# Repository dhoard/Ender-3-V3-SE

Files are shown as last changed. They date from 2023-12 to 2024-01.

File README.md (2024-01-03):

## Ender 3 V3 SE Mods

The project contains Ender3 V3 SE modifications.

[X-axis linear rail](https://github.com/dhoard/Ender3-V3-SE/tree/main/x-axis-linear-rail)

[3 Point Carriage Adapter](https://github.com/dhoard/Ender-3-V3-SE/tree/main/3-point-carriage-adapter)

## License
[CC BY-NC-SA 4.0](https://creativecommons.org/licenses/by-nc-sa/4.0/)

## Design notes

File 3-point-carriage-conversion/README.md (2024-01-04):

## 3 Point Carriage Conversion 

## Disclaimer

Install and use at your own risk. Not responsible for you, your machine, or any damages.

### Tools

A soldering iron or heat set insert tool is required

### Parts list:

1 x [3 Point Carriage Adapter (Top)](3%20Point%20Carriage%20Adapter%20%28Top%29.stl)
- PETG or ABS, 50% tri-hexagon infill, .3mm layer height, 8 walls

1 x [3 Point Carriage Adapter (Bottom)](3%20Point%20Carriage%20Adapter%20%28Bottom%29.stl)
- 50% tri-hexagon infill, .3mm layer height, 8 walls
- PETG or ABS

1 x [Bed Leveling Knob](Bed%20Leveling%20Knob.stl)

2 x Ender 3 25mm Yellow Springs

1 x M4 x 35mm screw

4 x M4 x 8mm screws

5 x M4 nuts

### Instructions

1. Unplug the printer
2. Remove the build surface
3. Remove the build plate
4. Use a heat set insert tool or soldering iron to set an M4 nut into the Bed Leveling Knob
5. Insert the M4 x 35mm screw into the 3 Point Carriage Adapter (Top) part
 - The fit is snug on purpose to help hold the screw
 - You may need to heat set the screw head into the part
6. Attach the 3 Point Carriage Adapter (Top) part to the right side of the build plate with 2 x M4 x 8mm screws and M4 nuts
7. Attached the 3 Point Carriage Adapter (Bottom) part to the right side of the carriage with 2 x M4 x 8mm screws and M4 nuts
- The ridges should be pointing up
8. Move a 16mm spacer from the right side to the left front corner (strain gauge)
9. Insert a spring between the left side rear build plate and wiring strain bracket
- **BE CAREFUL OR YOU COULD DAMAGE/DISCONNECT YOU BUILD PLATE HEATER WIRES**
10. Re-install the build plate
- When compressing the springs, compress (squeeze) the carriage and build plate together to compress the springs
- **DO NOT JUST PRESS ON THE BUILD PLATE OR YOU WILL BEND YOUR CARRIAGE**
- Use the the [Bed Leveling Knob](Bed%20Leveling%20Knob.stl) on the right side.
- This can be difficult due to limited space
11. Run bed leveling with a heated bed, adjust, and repeat

### Images

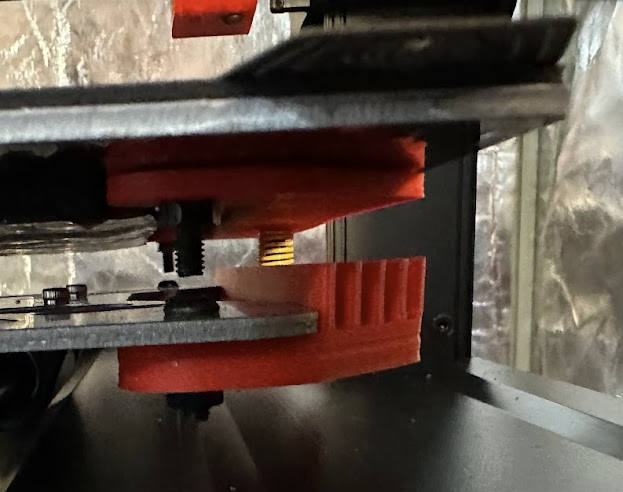
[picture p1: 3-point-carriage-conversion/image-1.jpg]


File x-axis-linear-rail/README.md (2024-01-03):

## X-axis linear rail

## Disclaimer

Install and use at your own risk. Not responsible for you, your machine, or any damages.

### Parts list:

1 x MGN9H 350mm linear rail (preferably with z1 preset loading (common))
- an MGN12 rail will NOT work due to the carriage width (27mm)

2 x [MGN9 linear rail spacer blocks - left](Ender%203%20V3%20SE%20MGN9%20linear%20rail%20spacer%20block%20-%20left.3mf)
- 50% cubic infill, .3mm layer height, 4 walls

5 x [MGN9 linear rail spacer blocks - center](Ender%203%20V3%20SE%20MGN9%20linear%20rail%20spacer%20block%20-%20center.3mf)
- 50% cubic infill, .3mm layer height, 4 walls

1 x [MGN9 linear rail spacer blocks - right](Ender%203%20V3%20SE%20MGN9%20linear%20rail%20spacer%20block%20-%20right.3mf)
- 50% cubic infill, .3mm layer height, 4 walls

1 x [MGN9H gantry mount](Ender-3-V3-SE/blob/main/x-axis-linear-rail/Ender%203%20V3%20SE%20MGN9%20gantry%20mount.3mf)
 - 50% cubic infill, .3mm layer height, 4 walls 

12 x  M3-0.5 x 16mm button head screws

8 x M3 hammer head t-nuts

2 x MGN9 alignment tool
 - [https://www.thingiverse.com/thing:4976160](MGN9%20alignment%20tool)

### Instructions

1. Unplug the printer
2. Detach the printer tool head cable
3. Loosen the x-axis belt
4. Disassembly the printer tool head
5. Detach the x-axis belt
6. Remove the printer tool head x-axis gantry plate
7. Disassembly the tool head
8. Remove the v-wheels, spacers, and bolts
9. Attach the MGN9 linear rail to the x-axis extrusion with the spacer blocks between the rail and extrusion. The goal it place spacers in ever other hole, starting with the left most spacer... but your rail holes/spacing may be different
--  The linear rail should be offset to the right so that carriage can go completely to the x-axis belt adjuster
11. Attach the tool head to the gantry mount
12. Attach the x-axis belt
13. Attach the gantry mount to the MGN9H carriage
14. Assemble the printer tool head
15. Tighten the x-axis belt
16. Attach the printer tool head cable

### Images

V1

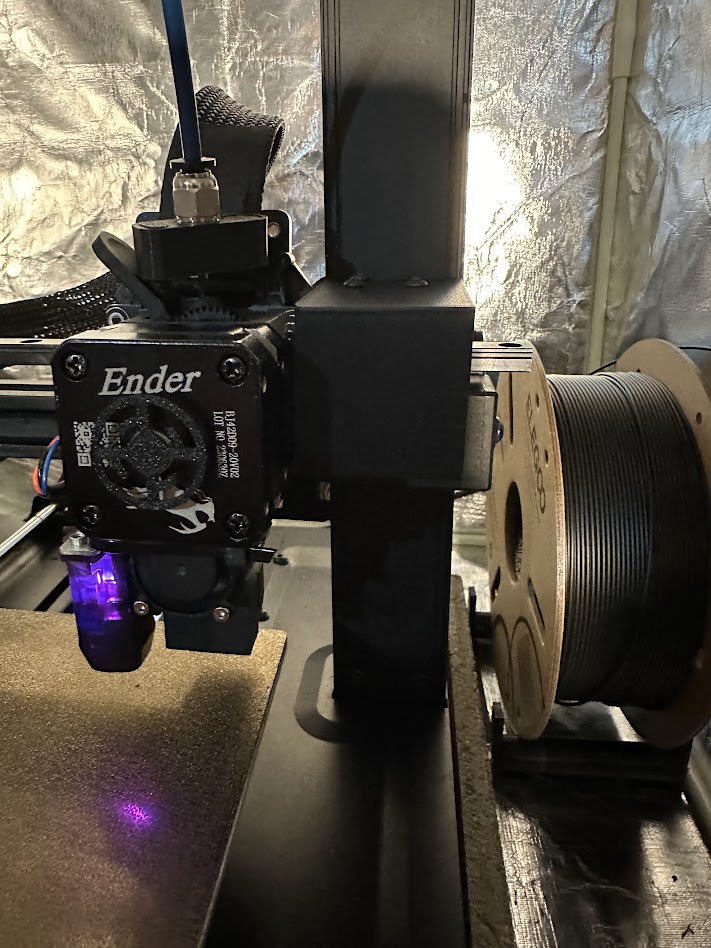
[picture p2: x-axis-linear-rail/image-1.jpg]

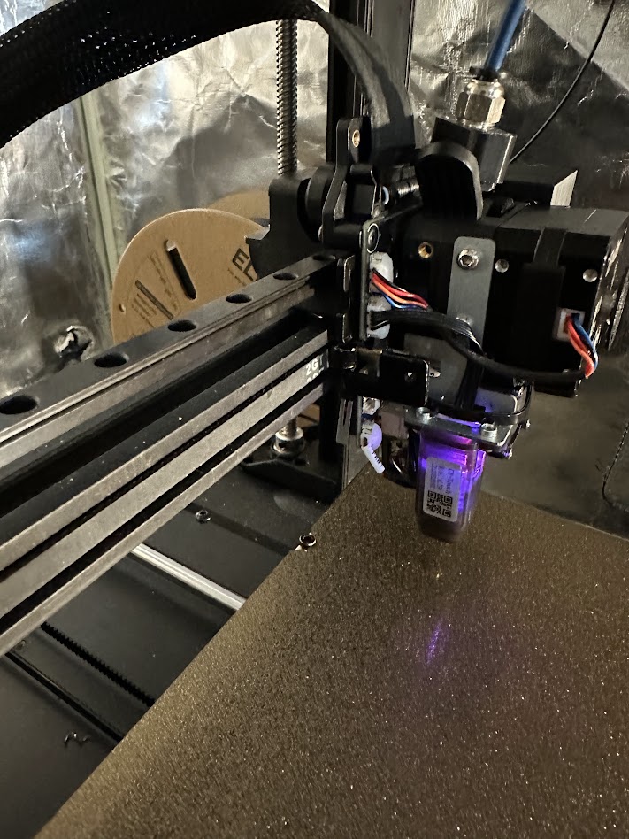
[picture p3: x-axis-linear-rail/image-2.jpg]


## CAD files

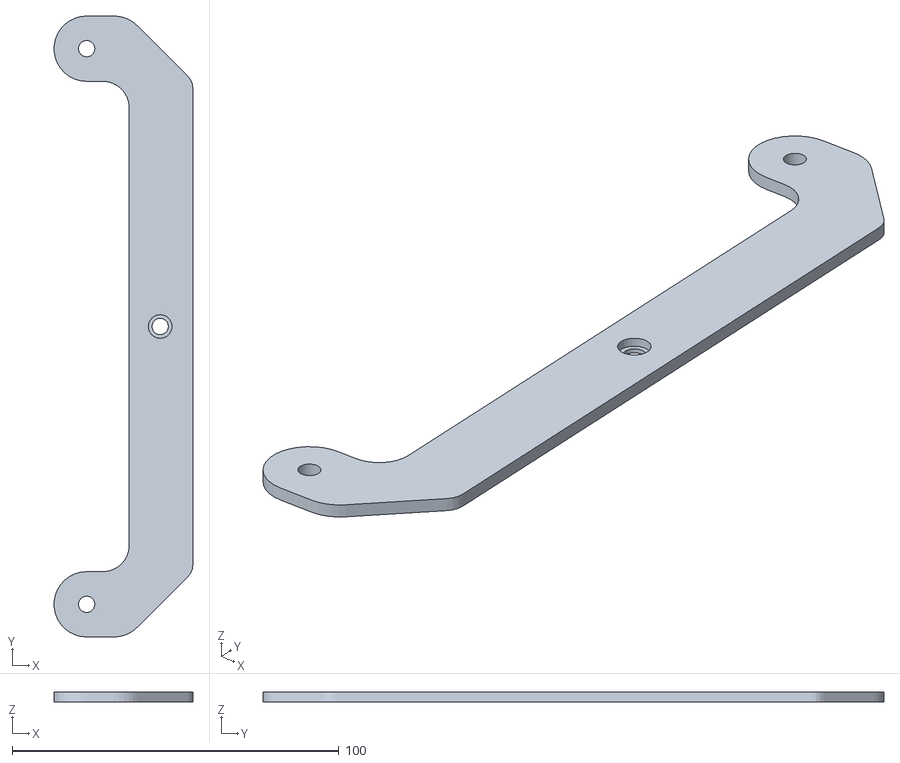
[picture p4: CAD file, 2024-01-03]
3-point-carriage-conversion/3 Point Carriage Adapter (Top).stl
42.5 x 190.0 x 3.00

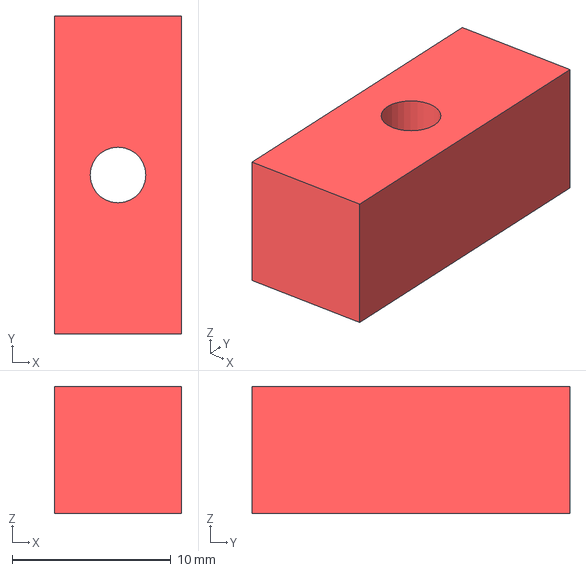
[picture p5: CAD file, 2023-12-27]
x-axis-linear-rail/Ender 3 V3 SE MGN9 linear rail spacer block - center.3mf
8.00 x 20.0 x 8.00 mm

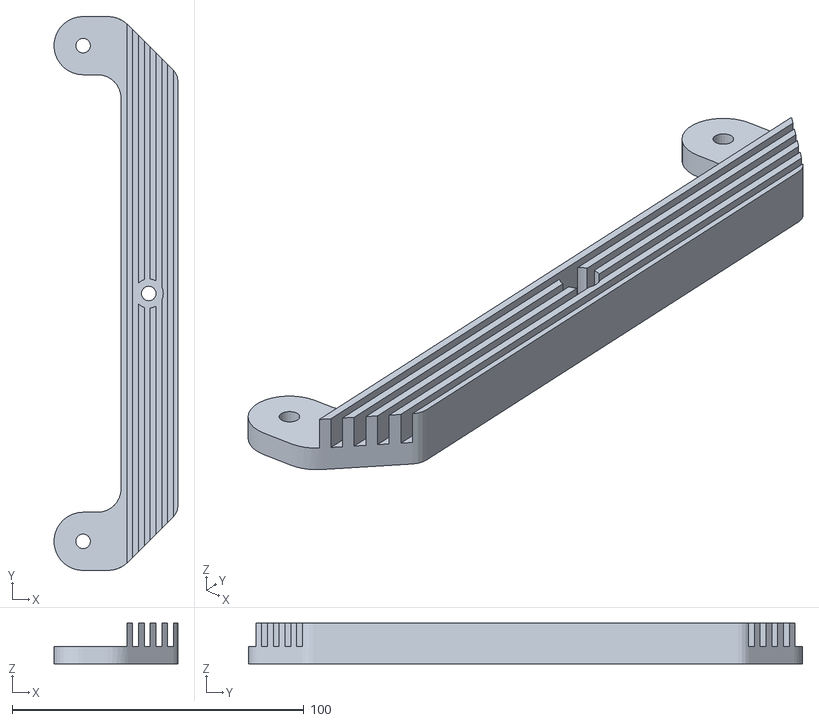
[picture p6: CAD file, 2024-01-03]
3-point-carriage-conversion/3 Point Carriage Adapter (Bottom).stl
42.5 x 190.0 x 14.0

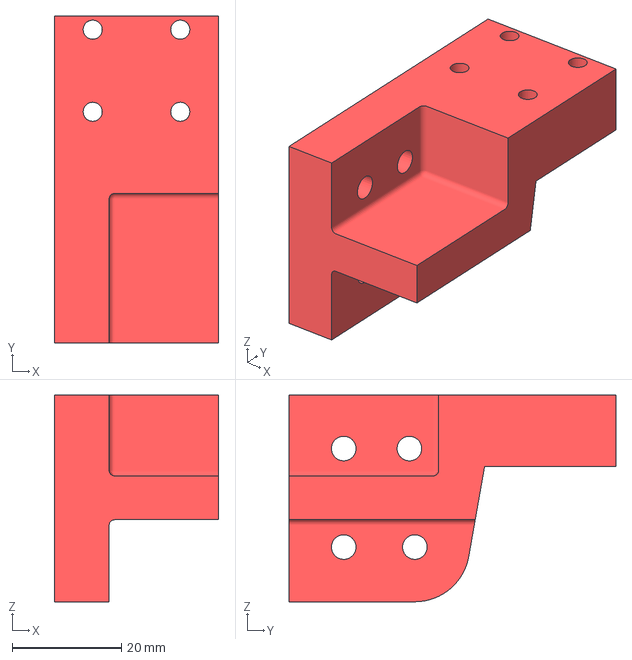
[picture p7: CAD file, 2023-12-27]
x-axis-linear-rail/Ender 3 V3 SE MGN9 gantry mount.3mf
30.0 x 59.8 x 37.8 mm

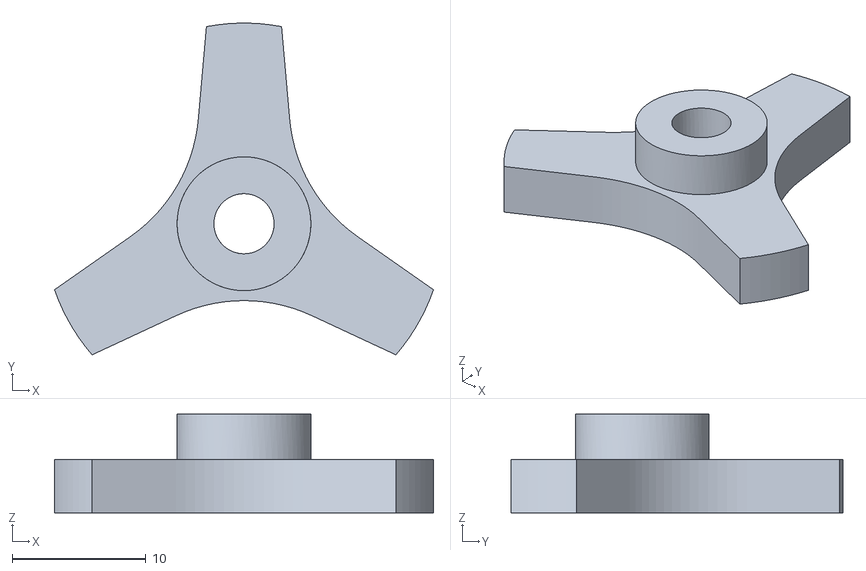
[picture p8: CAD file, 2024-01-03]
3-point-carriage-conversion/Bed Leveling Knob.stl
28.3 x 24.8 x 7.40

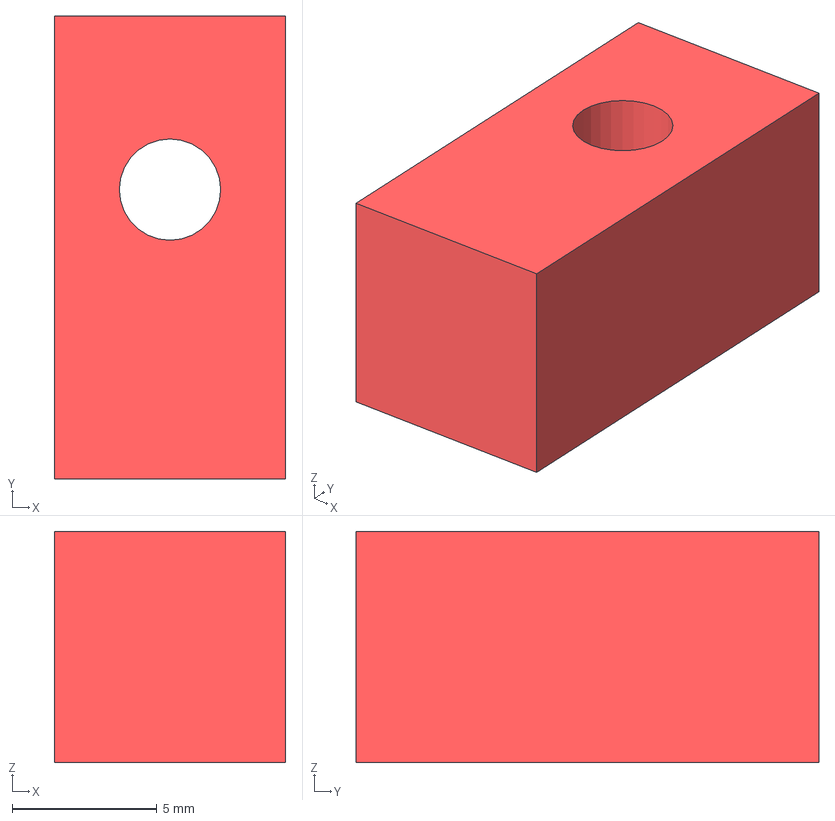
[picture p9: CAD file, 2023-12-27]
x-axis-linear-rail/Ender 3 V3 SE MGN9 linear rail spacer block - left.3mf
8.00 x 16.0 x 8.00 mm

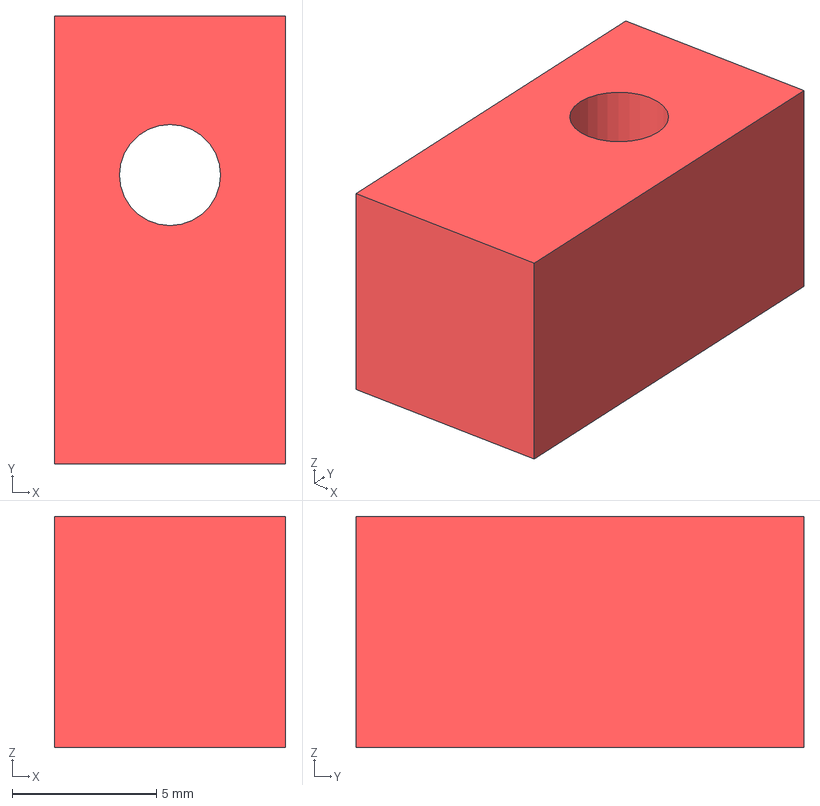
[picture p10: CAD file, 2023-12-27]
x-axis-linear-rail/Ender 3 V3 SE MGN9 linear rail spacer block - right.3mf
8.00 x 15.5 x 8.00 mm

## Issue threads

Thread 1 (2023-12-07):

Change linear rail recommendation

dhoard, 2023-12-07:
The MGN9 300mm rail works, but doesn't leave any margin of error on left/right alignment.

dhoard, 2023-12-08:
Changed linear rail recommendation to 350mm.

Closed 2023-12-08.

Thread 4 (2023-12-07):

Increase linear rail mount block holes

dhoard, 2023-12-07:
The linear rail mounting block holes are tight and need to be increased in size to allow for easier mounting/alignment.

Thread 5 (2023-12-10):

X-axis linear rail needs full length support

dhoard, 2023-12-10:
After purchasing two linear rails, I have determined they both have a very very minor bow.

Full support of the linear rail is required to remove the bow.

pwlgrzs, 2024-01-24:
Hi again @dhoard, Is this related to how the mesh ends up?

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

This is 10x10 mesh done after installation and I am not sure how to fix that.

dhoard, 2024-01-24:
WOW!!!

I would loosen your linear rail, then tighten it from the center out a little at a time/incrementally (center, left, right, further left, further right, etc.) Repeat the procedure until it's tight.

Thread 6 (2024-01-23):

What part cooling mount/fan to use?

pwlgrzs, 2024-01-23:
Hello,

I have installed your x-rail mod and it works great but I am having problem finding a good option for part cooling since the right side is not really usable at the moment, is there something you recommend?

dhoard, 2024-01-23:
@pwlgrzs Awesome it's working well for you! I am currently using https://www.thingiverse.com/thing:6297778/files specifically Duct_Left_Normal_Height_V2.stl.

pwlgrzs, 2024-01-23:
Great, thanks, I got it printed actually.

By the way do you plan to modify released design? I've seen Issues opened touching this matter.

dhoard, 2024-01-23:
I do, though have been busy waiting on parts to modify a V2 I just purchased to be able to easily print parts for the SE. I have designing, printing, disassembling, testing, reassembling the SE which is extremely slow.

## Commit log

2023-12-07 Added part files
    [Ender 3 V3 SE MGN9 linear rail spacer block.3mf, Ender 3 V3 SE MGN9H carriage mount.3mf, Ender 3 V3 SE x-axis endstop extension.3mf]
2023-12-08 Increased hole size
    [Ender 3 V3 SE MGN9 linear rail spacer block.3mf]
2023-12-08 Changed recommendation to 350mm linear rail
2023-12-15 Updated design
    [Ender 3 V3 SE MGN9 linear rail spacer block.3mf, Ender 3 V3 SE MGN9H carriage mount.3mf, Ender 3 V3 SE x-axis endstop extension.3mf]
2023-12-27 Revised design
    [Ender 3 V3 SE MGN9 gantry mount.3mf, Ender 3 V3 SE MGN9 linear rail spacer block - center.3mf, Ender 3 V3 SE MGN9 linear rail spacer block - left.3mf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]
2024-01-03 Added 3 point carriage adapter project
    [3 Point Carriage Adapter (Bottom).stl, 3 Point Carriage Adapter (Top).stl, Bed Leveling Knob.stl]
2024-01-03 Changed name
    [3 Point Carriage Adapter (Bottom).stl, 3 Point Carriage Adapter (Top).stl, Bed Leveling Knob.stl]
